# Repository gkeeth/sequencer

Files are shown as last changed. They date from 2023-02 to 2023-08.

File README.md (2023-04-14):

# 8-step CV sequencer

Simple 8-step, 0-5V CV sequencer for synthesizers.

* Each step has an adjustable CV (0-5V)
* Clock is internally generated, but can also be provided externally
* Internal clock has adjustable frequency and duty cycle
* CV and clock outputs

Powered from a 9V battery.

This is a KiCad v7 project.

## License
Hardware design files are licensed under a [Creative Commons Attribution-ShareAlike 4.0
International License][cc-by-sa].

[][cc-by-sa]

Code is licensed under the MIT license.

[][mit-link]

[cc-by-sa]: http://creativecommons.org/licenses/by-sa/4.0/
[cc-by-sa-image]: https://licensebuttons.net/l/by-sa/4.0/88x31.png
[cc-by-sa-shield]: https://img.shields.io/badge/License-CC%20BY--SA%204.0-lightgrey.svg
[mit-link]: https://opensource.org/licenses/MIT
[mit-shield]: https://img.shields.io/badge/License-MIT-yellow.svg

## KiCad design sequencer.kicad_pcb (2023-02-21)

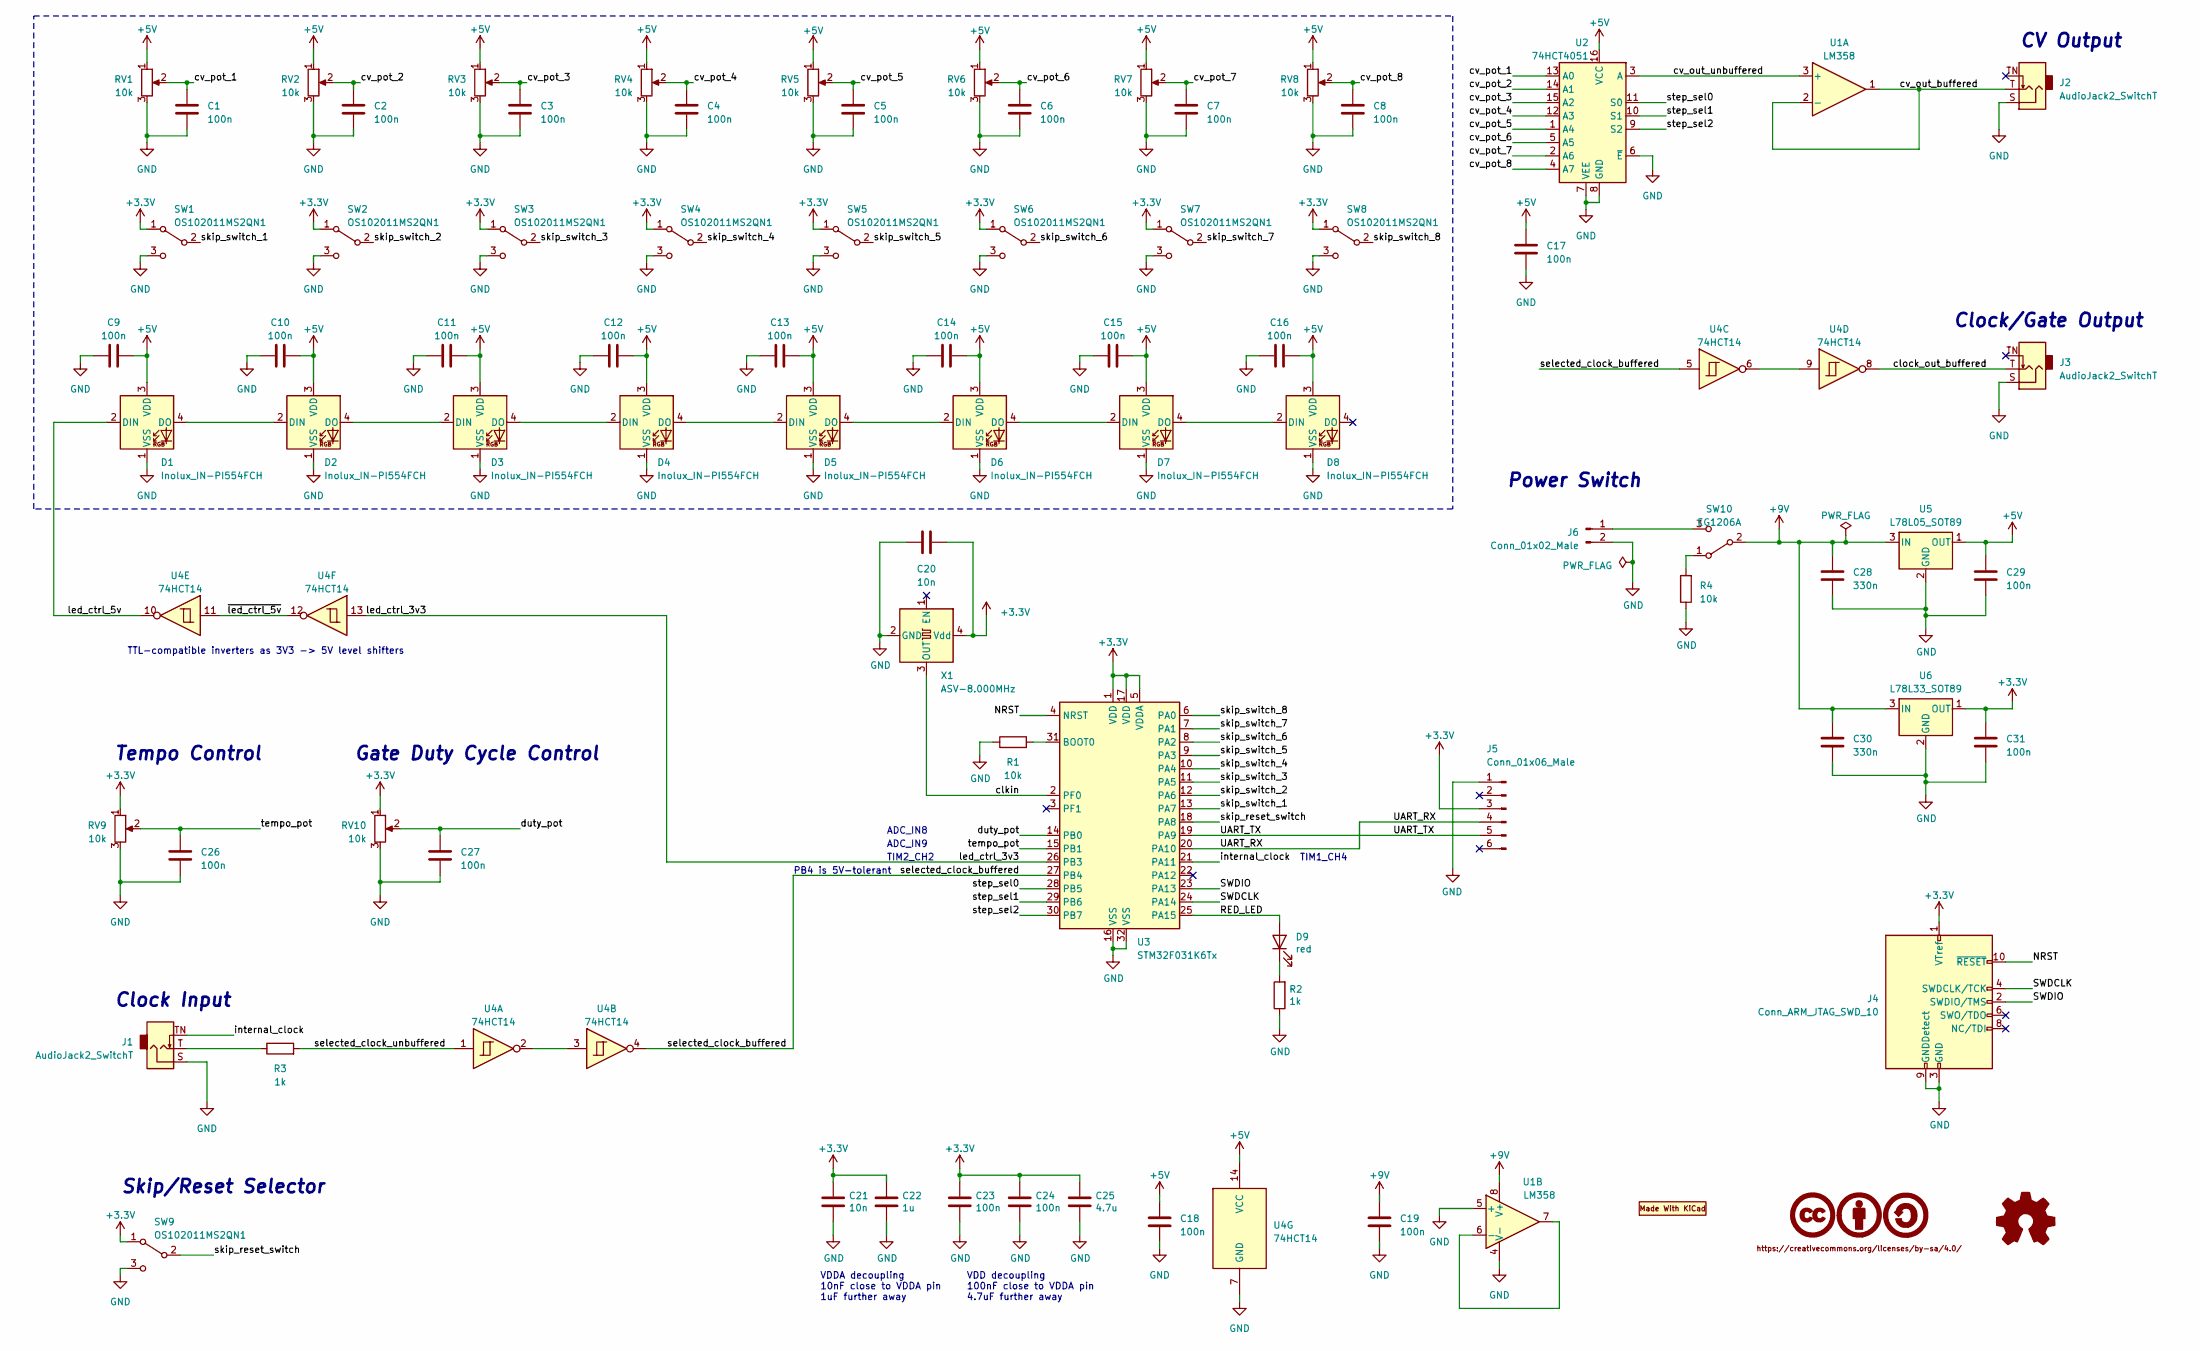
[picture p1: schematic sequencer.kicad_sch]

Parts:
C1, C2, C3, C4, C5, C6, C7, C8, C9, C10, C11, C12, C13, C14, C15, C16, C17, C18, C19, C23, C24, C26, C27, C29, C31: 100n; C_0603_1608Metric
C20, C21: 10n; C_0603_1608Metric
C22: 1u; C_0805_2012Metric; Manufacturer PN C0805C105K3RACTU
C25: 4.7u; C_0805_2012Metric; Manufacturer PN C0805C475K4RACTU
C28, C30: 330n; C_0805_2012Metric
D1, D2, D3, D4, D5, D6, D7, D8: Inolux_IN-PI554FCH; LED_Inolux_IN-PI554FCH_PLCC4_5.0x5.0mm_P3.2mm
D9: red; LED_0603_1608Metric; Manufacturer PN LTST-C191KRKT
J1, J2, J3: AudioJack2_SwitchT; Jack_3.5mm_QingPu_WQP-PJ398SM_Vertical_CircularHoles
J4: Conn_ARM_JTAG_SWD_10; PinHeader_2x05_P1.27mm_Vertical_SMD
J5: Conn_01x06_Male; PinHeader_1x06_P2.54mm_Horizontal
J6: Conn_01x02_Male; Molex_SL_A-70553-0001_1x02_P2.54mm_Horizontal
LOGO1: CC-BY-SA_0.33in; CC-BY-SA_SilkScreenTop_Small
LOGO2: Logo_MadeWithKiCad; KiCad-Logo2_5mm_SilkScreen
LOGO3: Logo_Open_Hardware_Small; OSHW-Logo2_7.3x6mm_SilkScreen
R1, R4: 10k; R_0603_1608Metric
R2: 1k; R_0603_1608Metric; Manufacturer PN RT0603FRE071KL
R3: 1k; R_0603_1608Metric
RV1, RV2, RV3, RV4, RV5, RV6, RV7, RV8, RV9, RV10: 10k; Potentiometer_Bourns_PTV09A-1_Single_Vertical; Manufacturer PN PTV09A-4020F-B103
SW1, SW2, SW3, SW4, SW5, SW6, SW7, SW8, SW9: OS102011MS2QN1; SW_Slide_1P2T_CK_OS102011MS2Q
SW10: EG1206A; SW_Slide_SPDT_E-Switch_EG1206A; Manufacturer PN EG1206A
U1: LM358; SOIC-8_3.9x4.9mm_P1.27mm
U2: 74HCT4051; SOIC-16_3.9x9.9mm_P1.27mm
U3: STM32F031K6Tx; LQFP-32_7x7mm_P0.8mm
U4: 74HCT14; SOIC-14_3.9x8.7mm_P1.27mm
U5: L78L05_SOT89; SOT-89-3
U6: L78L33_SOT89; SOT-89-3
X1: ASV-8.000MHz; Oscillator_SMD_Abracon_ASV-4Pin_7.0x5.1mm

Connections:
+3.3V: C20.1, C21.1, C22.1, C23.1, C24.1, C25.1, C31.2, J4.1 (VTref), J5.3, RV9.1, RV10.1, SW1.1 (A), SW2.1 (A), SW3.1 (A), SW4.1 (A), SW5.1 (A), SW6.1 (A), SW7.1 (A), SW8.1 (A), SW9.1 (A), U3.1 (VDD), U3.5 (VDDA), U3.17 (VDD), U6.1 (OUT), X1.4 (Vdd)
+5V: C9.1, C10.1, C11.1, C12.1, C13.1, C14.1, C15.1, C16.1, C17.2, C18.2, C29.2, D1.3 (VDD), D2.3 (VDD), D3.3 (VDD), D4.3 (VDD), D5.3 (VDD), D6.3 (VDD), D7.3 (VDD), D8.3 (VDD), RV1.1, RV2.1, RV3.1, RV4.1, RV5.1, RV6.1, RV7.1, RV8.1, U2.16 (VCC), U4.14 (VCC), U5.1 (OUT)
+9V: C19.2, C28.1, C30.1, SW10.2 (B), U1.8 (V+), U5.3 (IN), U6.3 (IN)
/NRST: J4.10 (~RESET), U3.4 (NRST)
/RED_LED: D9.2 (A), U3.25 (PA15)
/SWDCLK: J4.4 (SWDCLK/TCK), U3.24 (PA14)
/SWDIO: J4.2 (SWDIO/TMS), U3.23 (PA13)
/UART_RX: J5.4, U3.20 (PA10)
/UART_TX: J5.5, U3.19 (PA9)
/clkin: U3.2 (PF0), X1.3 (OUT)
/clock_out_buffered: J3.T, U4.8
/cv_out_buffered: J2.T, U1.1, U1.2 (-)
/cv_out_unbuffered: U1.3 (+), U2.3 (A)
/cv_pot_1: C1.2, RV1.2, U2.13 (A0)
/cv_pot_2: C2.2, RV2.2, U2.14 (A1)
/cv_pot_3: C3.2, RV3.2, U2.15 (A2)
/cv_pot_4: C4.2, RV4.2, U2.12 (A3)
/cv_pot_5: C5.2, RV5.2, U2.1 (A4)
/cv_pot_6: C6.2, RV6.2, U2.5 (A5)
/cv_pot_7: C7.2, RV7.2, U2.2 (A6)
/cv_pot_8: C8.2, RV8.2, U2.4 (A7)
/duty_pot: C27.2, RV10.2, U3.14 (PB0)
/internal_clock: J1.TN, U3.21 (PA11)
/led_ctrl_3v3: U3.26 (PB3), U4.13
/led_ctrl_5v: D1.2 (DIN), U4.10
/selected_clock_buffered: U3.27 (PB4), U4.4, U4.5
/selected_clock_unbuffered: R3.2, U4.1
/skip_reset_switch: SW9.2 (B), U3.18 (PA8)
/skip_switch_1: SW1.2 (B), U3.13 (PA7)
/skip_switch_2: SW2.2 (B), U3.12 (PA6)
/skip_switch_3: SW3.2 (B), U3.11 (PA5)
/skip_switch_4: SW4.2 (B), U3.10 (PA4)
/skip_switch_5: SW5.2 (B), U3.9 (PA3)
/skip_switch_6: SW6.2 (B), U3.8 (PA2)
/skip_switch_7: SW7.2 (B), U3.7 (PA1)
/skip_switch_8: SW8.2 (B), U3.6 (PA0)
/step_sel0: U2.11 (S0), U3.28 (PB5)
/step_sel1: U2.10 (S1), U3.29 (PB6)
/step_sel2: U2.9 (S2), U3.30 (PB7)
/tempo_pot: C26.2, RV9.2, U3.15 (PB1)
/~led_ctrl_5v: U4.11, U4.12
GND: C1.1, C2.1, C3.1, C4.1, C5.1, C6.1, C7.1, C8.1, C9.2, C10.2, C11.2, C12.2, C13.2, C14.2, C15.2, C16.2, C17.1, C18.1, C19.1, C20.2, C21.2, C22.2, C23.2, C24.2, C25.2, C26.1, C27.1, C28.2, C29.1, C30.2, C31.1, D1.1 (VSS), D2.1 (VSS), D3.1 (VSS), D4.1 (VSS), D5.1 (VSS), D6.1 (VSS), D7.1 (VSS), D8.1 (VSS), J1.S, J2.S, J3.S, J4.3 (GND), J4.5 (GND), J4.9 (GNDDetect), J5.1, J6.2, R1.1, R2.1, R4.1, RV1.3, RV2.3, RV3.3, RV4.3, RV5.3, RV6.3, RV7.3, RV8.3, RV9.3, RV10.3, SW1.3 (C), SW2.3 (C), SW3.3 (C), SW4.3 (C), SW5.3 (C), SW6.3 (C), SW7.3 (C), SW8.3 (C), SW9.3 (C), U1.4 (V-), U1.5 (+), U2.6 (~E), U2.7 (VEE), U2.8 (GND), U3.16 (VSS), U3.32 (VSS), U4.7 (GND), U5.2 (GND), U6.2 (GND), X1.2 (GND)
unnamed: D1.4 (DO), D2.2 (DIN)
unnamed: D2.4 (DO), D3.2 (DIN)
unnamed: D3.4 (DO), D4.2 (DIN)
unnamed: D4.4 (DO), D5.2 (DIN)
unnamed: D5.4 (DO), D6.2 (DIN)
unnamed: D6.4 (DO), D7.2 (DIN)
unnamed: D7.4 (DO), D8.2 (DIN)
unnamed: D9.1 (K), R2.2
unnamed: J1.T, R3.1
unnamed: J6.1, SW10.3 (C)
unnamed: R4.2, SW10.1 (A)
unnamed: U1.6 (-), U1.7
unnamed: R1.2, U3.31 (BOOT0)
unnamed: U4.2, U4.3
unnamed: U4.6, U4.9

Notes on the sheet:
ADC_IN9
CV Output
Gate Duty Cycle Control
Tempo Control
Clock Input
VDDA decoupling 10nF close to VDDA pin 1uF further away
TIM1_CH4
Skip/Reset Selector
VDD decoupling 100nF close to VDDA pin 4.7uF further away
Clock/Gate Output
ADC_IN8
TIM2_CH2
TTL-compatible inverters as 3V3 -> 5V level shifters
PB4 is 5V-tolerant
Power Switch

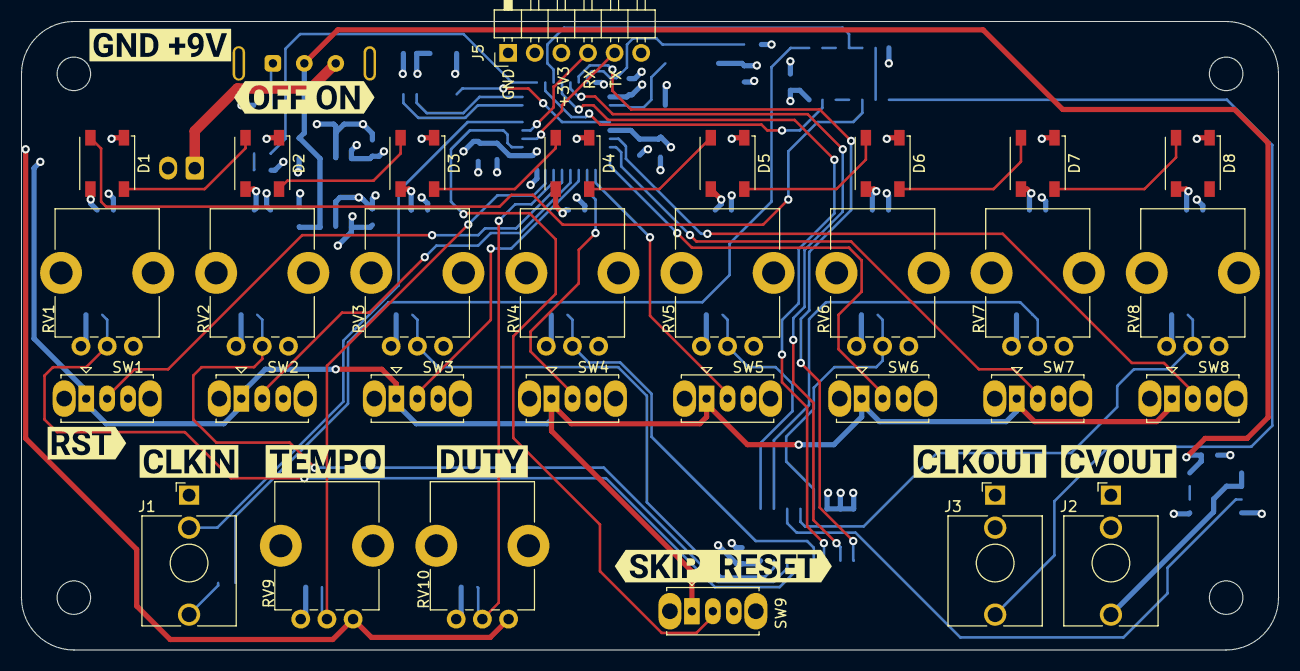
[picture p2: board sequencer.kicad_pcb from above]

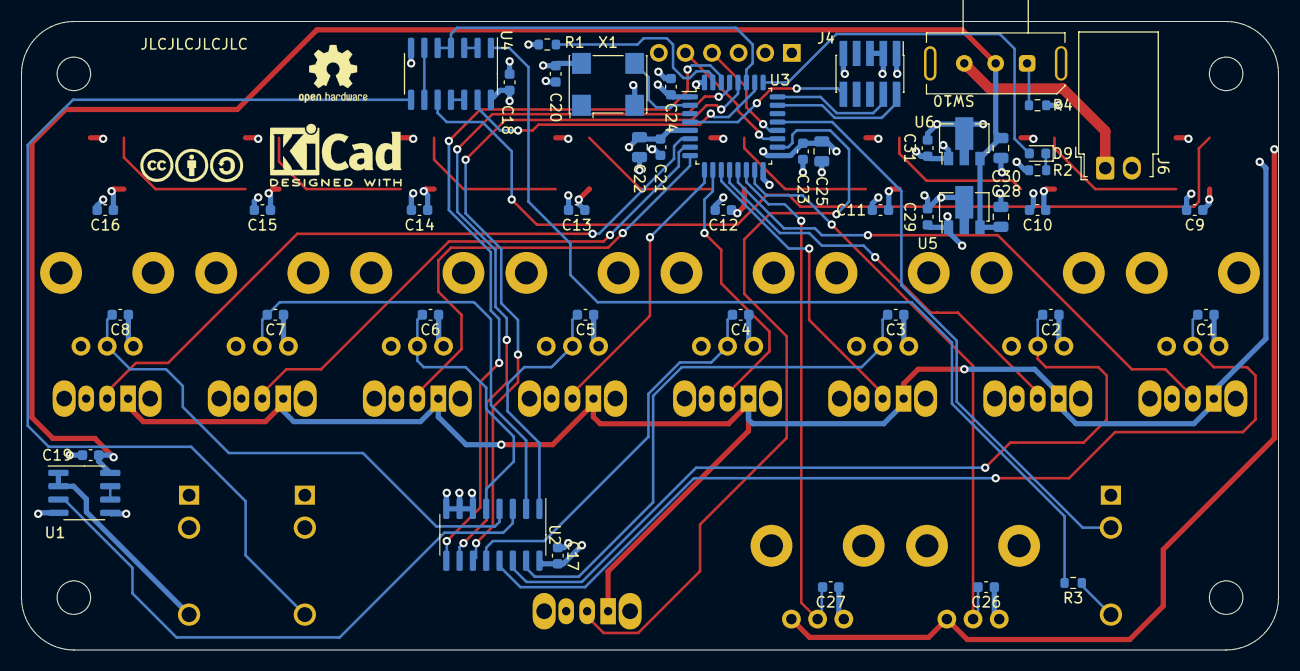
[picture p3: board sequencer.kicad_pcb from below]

Board: 4 copper layers, 120.0 x 60.0 mm, 89 parts (49 on the bottom side), 57 nets.

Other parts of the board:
kibuzzard-63F425C8: G***; kibuzzard-63F425C8
kibuzzard-63F425D0: G***; kibuzzard-63F425D0
kibuzzard-63F427E2: G***; kibuzzard-63F427E2
kibuzzard-63F428B8: G***; kibuzzard-63F428B8
kibuzzard-63F428D5: G***; kibuzzard-63F428D5
kibuzzard-63F42616: G***; kibuzzard-63F42616
kibuzzard-63F42620: G***; kibuzzard-63F42620
kibuzzard-63F42641: G***; kibuzzard-63F42641
kibuzzard-63F42779: G***; kibuzzard-63F42779

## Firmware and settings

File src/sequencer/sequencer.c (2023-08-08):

#include <stdint.h>

#include "sequencer.h"
#include "system_clocks.h"
#include "led.h"
#include "uart.h"
#include "tempo_and_duty.h"
#include "steps.h"
#include "utils.h"

static void setup(void) {
    clock_setup();

    board_led_setup();
    uart_setup();
    init_tempo_and_duty_pots();
    switch_setup();
    mux_setup();
    setup_tempo_and_duty_adc();
    setup_sequencer_clockin();

    // wait 20ms for initial debounced pot and switch values to be ready before
    // we enable the sequencer clkout and step LEDs
    // (both the step switches and the tempo/duty ADC need 16ms)
    uint32_t t0 = millis();
    while ((millis() - t0) < 20U) {};

    setup_sequencer_clockout();
    set_tempo_and_duty(get_tempo_pot_bpm_tenths(), get_duty_pot_percent());
    setup_step_leds_timer();
}

int main(void) {
    const uint32_t BLINK_DELAY = 500;
    const uint32_t ADC_PRINT_DELAY = 800;

    setup();
    uint32_t last_flash_millis = millis();
    uint32_t last_adc_print_millis = last_flash_millis;

    while (1) {
        if ((millis() - last_flash_millis) > BLINK_DELAY) {
            board_led_toggle();
            last_flash_millis = millis();
        }

        uint32_t duty_percent = get_duty_pot_percent();
        uint32_t tempo_raw = get_tempo_pot_value();
        uint32_t tempo_bpm_tenths = get_tempo_pot_bpm_tenths();
        uint32_t tempo_bpm = tempo_bpm_tenths * 10;

        if ((millis() - last_adc_print_millis) > ADC_PRINT_DELAY) {
            uart_send_string("tempo (raw): ");
            uart_send_number((int32_t) tempo_raw);
            uart_send_string("tempo (bpm): ");
            uart_send_number((int32_t) tempo_bpm);
            uart_send_string("duty (raw): ");
            uart_send_number((int32_t) get_duty_pot_value());

            uart_send_string("debounced skip/reset switch: ");
            if (get_skip_reset_switch() == SWITCH_SKIP) {
                uart_send_string("SKIP\r\n");
            } else {
                uart_send_string("RESET\r\n");
            }

            uart_send_string("debounced step switch values: ");
            uart_send_number((int32_t) get_step_switches());

            uart_send_string("current step: ");
            uart_send_number((int32_t) get_current_step());

            uart_send_line("");

            last_adc_print_millis = millis();
        }

        set_tempo_and_duty(tempo_bpm_tenths, duty_percent);

        uart_echo();
    }

    return 0;
}

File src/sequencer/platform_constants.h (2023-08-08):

#ifndef PLATFORM_CONSTANTS_H
#define PLATFORM_CONSTANTS_H

#include "sequencer.h"

#define SYSCLK_FREQ_MHZ 48U
#define SYSCLK_FREQ_HZ (SYSCLK_FREQ_MHZ * 1000000U)

#define USART USART1
#define RCC_USART RCC_USART1
#define RCC_UART_GPIO RCC_GPIOA
#define PORT_UART GPIOA
#define PIN_UART_TX GPIO9
#define PIN_UART_RX GPIO10

#define PORT_ADC GPIOB
#define RCC_ADC_GPIO RCC_GPIOB
#define PIN_DUTY GPIO0
#define PIN_TEMPO GPIO1
#define ADC_CHANNEL_DUTY 8
#define ADC_CHANNEL_TEMPO 9
#define RCC_ADC_TIMER RCC_TIM3
#define RCC_ADC_DMA RCC_DMA1
#define ADC_DMA DMA1
#define ADC_DMA_CHANNEL DMA_CHANNEL1
#define ADC_DR_ADDRESS ((uint32_t) &ADC1_DR)
#define ADC_DBG_TIM_STOP DBGMCU_CR_TIM3_STOP
#define ADC_TIMER TIM3
#define ADC_TIMER_TRIGGER ADC_CFGR1_EXTSEL_TIM3_TRGO
#define ADC_TRIGGER_RATE_HZ 1000U
#define ADC_BLOCK_SIZE 16U
#define ADC_BUFFER_SIZE (ADC_BLOCK_SIZE * 4)

#define PORT_STATUS_LED GPIOA
#define PIN_STATUS_LED GPIO15
#define RCC_STATUS_LED_GPIO RCC_GPIOA
#define PORT_LEDS GPIOB
#define PIN_LEDS GPIO3
#define LEDS_TIMER TIM2
#define LEDS_TIM_IRQ NVIC_TIM2_IRQ
#define LEDS_TIM_OC TIM_OC2
#define LEDS_TIM_CCR_ADDRESS ((uint32_t) &TIM_CCR2(LEDS_TIMER))
#define LEDS_DMA DMA1
#define LEDS_DMA_CHANNEL DMA_CHANNEL3
#define LEDS_TIM_DMA_IRQ NVIC_DMA1_CHANNEL2_3_DMA2_CHANNEL1_2_IRQ
#define LEDS_GPIO_AF GPIO_AF2
#define RCC_LEDS_GPIO RCC_GPIOB
#define RCC_LEDS_TIMER RCC_TIM2
#define RCC_LEDS_DMA RCC_DMA1
#define LED_DATA_PERIOD_NS 1200U
#define LED_RESET_PERIOD_NS 80000U
#define LED_DATA_ARR (SYSCLK_FREQ_MHZ * LED_DATA_PERIOD_NS / 1000U - 1U) // 56, ideally 56.6
#define LED_RESET_ARR (SYSCLK_FREQ_MHZ * LED_RESET_PERIOD_NS / 1000U - 1U)
#define LED_DATA0_DUTY 25U
#define LED_DATA1_DUTY 50U
#define LED_DATA0_CCR ((LED_DATA_ARR + 1U) * LED_DATA0_DUTY / 100U - 1U) // 13, ideally 13.4
#define LED_DATA1_CCR ((LED_DATA_ARR + 1U) * LED_DATA1_DUTY / 100U - 1U) // 27, ideally 27.8
#define LED_BUFFER_SIZE (NUM_STEPS * 3U * 8U + 1U)
#define LED_STEP_ACTIVE_RED     0x20
#define LED_STEP_ACTIVE_GREEN   0x00
#define LED_STEP_ACTIVE_BLUE    0x00
#define LED_STEP_INACTIVE_RED   0x00
#define LED_STEP_INACTIVE_GREEN 0x00
#define LED_STEP_INACTIVE_BLUE  0x08
#define LED_STEP_DISABLED_RED   0x00
#define LED_STEP_DISABLED_GREEN 0x00
#define LED_STEP_DISABLED_BLUE  0x00

// each high LSB is a debounce cycle
#define CLKIN_DEBOUNCE_MASK 0x000F
#define RCC_SEQCLKIN_GPIO RCC_GPIOB
#define PORT_SEQCLKIN GPIOB
#define PIN_SEQCLKIN GPIO4

#define RCC_SEQCLKOUT_GPIO RCC_GPIOA
#define RCC_SEQCLKOUT_TIMER RCC_TIM1
#define PORT_SEQCLKOUT GPIOA
#define PIN_SEQCLKOUT GPIO11
#define SEQCLKOUT_TIMER TIM1
#define SEQCLKOUT_TIM_OC TIM_OC4
#define SEQCLKOUT_GPIO_AF GPIO_AF2
#define SEQCLKOUT_FREQ_HZ 1000U
#define TIMER_PRESCALER 2000U

#define RCC_SWITCH_GPIO RCC_GPIOA
#define PORT_SWITCH GPIOA
#define PIN_SWITCH_STEP0 GPIO7
#define PIN_SWITCH_STEP1 GPIO6
#define PIN_SWITCH_STEP2 GPIO5
#define PIN_SWITCH_STEP3 GPIO4
#define PIN_SWITCH_STEP4 GPIO3
#define PIN_SWITCH_STEP5 GPIO2
#define PIN_SWITCH_STEP6 GPIO1
#define PIN_SWITCH_STEP7 GPIO0
#define PIN_SWITCH_SKIP_RESET GPIO8
#define PIN_SWITCHES (PIN_SWITCH_SKIP_RESET | PIN_SWITCH_STEP0 | PIN_SWITCH_STEP1 \
        | PIN_SWITCH_STEP2 | PIN_SWITCH_STEP3 | PIN_SWITCH_STEP4 \
        | PIN_SWITCH_STEP5 | PIN_SWITCH_STEP6 | PIN_SWITCH_STEP7)

#define TICK_TIMER TIM14
#define RCC_TICK_TIMER RCC_TIM14
#define TICK_TIMER_ISR tim14_isr
#define TICK_TIMER_IRQ NVIC_TIM14_IRQ
#define TICK_RATE_HZ 1000U

#define RCC_MUX_GPIO RCC_GPIOB
#define PORT_MUX GPIOB
#define PIN_MUX_SEL0 GPIO5
#define PIN_MUX_SEL1 GPIO6
#define PIN_MUX_SEL2 GPIO7

#endif // PLATFORM_CONSTANTS_H

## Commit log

2022-12-18 Complete TODOs
    - assign all footprints except pots
    - hook up duty cycle pot
    - add power switch
    - switch to HCT inverters for logic level compatibility with 3.3V CMOS
    [sequencer.kicad_sch]
2022-12-18 add footprints to pots
    [sequencer.kicad_sch]
2022-12-18 mostly complete placement
    [sequencer.kicad_pcb, sequencer.kicad_sch]
2022-12-19 initial routing complete, DRC errors clean
    [sequencer.kicad_pcb, sequencer.kicad_sch]
2022-12-19 DRC clean, moved refdeses
    [sequencer.kicad_pcb]
2022-12-19 Circuit fixes and cleanup
    - minor schematic rearranging
    - checking I/O levels between MCU and 5V logic (still need to check
    switch selection bits)
    - change switches to 3V3, re-route
    [sequencer.kicad_pcb, sequencer.kicad_sch]
2022-12-28 clarify kicad v7
2023-01-14 change analog switch to HCT
    [sequencer.kicad_pcb, sequencer.kicad_sch]
2023-02-21 add labels
    [sequencer.kicad_pcb]
2023-02-21 update pot footprints from library
    [sequencer.kicad_pcb]
2023-02-21 r0 fab
    [sequencer.kicad_pcb, sequencer.kicad_sch]
2023-03-11 add basic code (just blink and uart)
    [stm32f0_basic.cfg]
2023-03-11 add TODO list for next hw rev
    [sequencer.kicad_sch]
2023-03-12 add ADC functionality for reading tempo and duty pots
2023-03-14 roughly working unit test framework
2023-03-22 uart with tests
2023-03-23 add uart send string/line functions
2023-03-23 add uart printing to assert
2023-03-23 move uart setup out of main file
2023-03-24 abstract uart echoing out into the uart driver
2023-03-25 move ADC reads, average updates into pot driver
2023-03-26 make adc trigger off of tim3
2023-03-28 add debounced switch driver
2023-03-29 move board led control into its own driver
2023-04-05 Rough PWM working
2023-04-05 Remove some PWM debug code
2023-04-05 Make PWM code more generic for 2 peripherals
2023-04-14 Complete timer_ms_to_arr tests, with assertions
2023-04-19 Add tests for duty_to_pwm_compare()
    - fix existing tests for function signature changes
    - fix a bug in duty_to_pwm_compare() allowing div-by-zero and remove now
    unnecessary code
    [platform_utils_test.cpp]
2023-04-21 Switch language server tooling to .ccls
    compile_commands.json needed to be regenerated for every new file, and
    bear doesn't work super well on mac with non-standard compilers (e.g.
    arm-none-eabi-gcc)
2023-04-22 Add unit tests and asserts for timer_hz_to_arr()
2023-04-22 Implement + test timer_ns_to_arr()
2023-04-22 Avoid some implicit conversions
    [sequencer.c]
2023-04-22 Fix a lot of warnings
    [platform_uart.c, sequencer.c, tempo_and_duty.c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]
2023-04-22 Add an additional assert in timer_ns_to_arr()
2023-04-28 Gross code to get LED DMA working
2023-04-28 Working LED PWM prototype
    ADC temporarily disabled because it interferes with the LED PWM and
    locks the part...
    [platform_constants.h, sequencer.c]
2023-04-30 Refactor pot reading/averaging
    (prep for using a ping pong DMA'd buffer for pot readings)
2023-05-02 More work for ADC DMA
2023-05-02 Get ADC DMA working (but it breaks LED DMA)
2023-05-02 temporarily fix LEDs
2023-05-03 Some cleanup of PWM/LED setup
2023-05-04 Refactoring
    - pwm.{c,h} didn't have anything meaningful in it, merged with
    tempo_and_duty.{c,h}
    - renamed some functions to be more clear
    - moved some function comments from c files to h files
    - improved some function comments
    [platform_adc.c, sequencer.c, tempo_and_duty.c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]
2023-05-05 Enable all 8 step LEDs
    for now they just toggle through christmas tree colors.
    Also make the LEDs less blindingly bright
2023-05-13 Reorganize switch debouncing constants
2023-05-13 step_leds: add led_set_for_step() and tests
    doesn't yet handle disabled/skipped steps
    [platform_constants.h]
2023-05-13 add comments for ideal PWM compare values
2023-05-19 Implement basic LED step toggling
    - hardcoded tempo and switches
    - BUG: when first LED resets, the remaining LEDs don't light up
    [platform_constants.h]
2023-05-19 Fix LED bug when first step was disabled
    Also rename some LED functions
2023-05-20 Implement reading/debouncing switches
2023-05-25 Make appropriate step leds come up on reset
    - don't hardcode initial leds to all red
    - note: switches aren't debounced for 16ms so initial state of disabled
    switches is incorrect until the first step after a full debounce
    cycle. This could be fixed by delaying for 16ms before turning on the
    lights (16ms is probably not noticeable), by preloading the debounced
    switch state (not ideal), or by changing the debounce algorithm.
    [sequencer.c]
2023-05-25 Factor read switches/set led buffer into a helper
2023-05-25 Make many step LED functions static
    - move LED buffer into platform_pwm.c and out of steps.c as it is a DMA
    buffer
    - make step LED functions that don't get called by outside customers
    static
    - unit tests currently broken, as static functions are not testable
    directly
2023-07-11 rename confusing switch function
2023-07-16 Fixup initial setup to not use hardcoded values
    [sequencer.c]
2023-08-05 WIP, not working refactor. Builds but LEDs don't work.
    [led.h, platform.c, sequencer.c]
2023-08-08 Fix LEDs in refactor
    DMA channel needs to be disabled when it's set up. The refactored
    code would trigger the dma (enable the channel) every time the timer
    interrupt fired, which started prior to DMA setup.
2023-08-08 Merge platform_pwm.c into platform.c
    There's a lot of coupling with shared buffers and overlap in
    functionality. It simplifies things to combine them even if the
    resulting file is quite long.
2023-08-08 Refactor tick timer interrupt
    also clean some TODOs and improve documentation

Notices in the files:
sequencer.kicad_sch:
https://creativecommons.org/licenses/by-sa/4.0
